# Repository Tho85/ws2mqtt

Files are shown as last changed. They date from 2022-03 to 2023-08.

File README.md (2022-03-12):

# ws2mqtt - WiSafe2 to MQTT gateway

ws2mqtt is an inofficial gateway to connect WiSafe2 smoke, heat and CO detectors to your smart home.

The gateway consists of an ESP32 module that handles Wifi and MQTT communication and integrates with Home Assistant through MQTT auto discovery. It is connected to an Arduino that acts as an SPI/UART converter. The Arduino talks to an official WiSafe2 module that is connected to your smoke detector network.

## Disclaimer

This project is not related to or endorsed by the manufacturer of WiSafe2 devices. It is an unofficial hobby project.

:warning: **DO NOT USE THIS PROJECT FOR SAFETY-CRITICAL PURPOSES!** :warning:

This is a hobby project after all, so do not rely on it for your personal safety or the saftey of others. Always assume that it will not work in a case of emergency, and plan your emergency procedures accordingly. As the [license](LICENSE.md) states in more detail, I won't be liable for any damages incurred by this project.

## Pictures

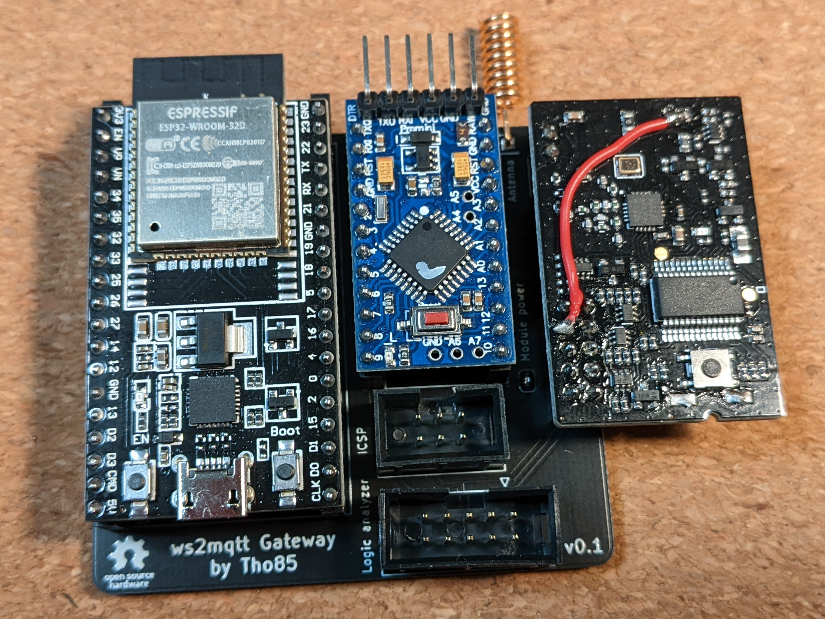
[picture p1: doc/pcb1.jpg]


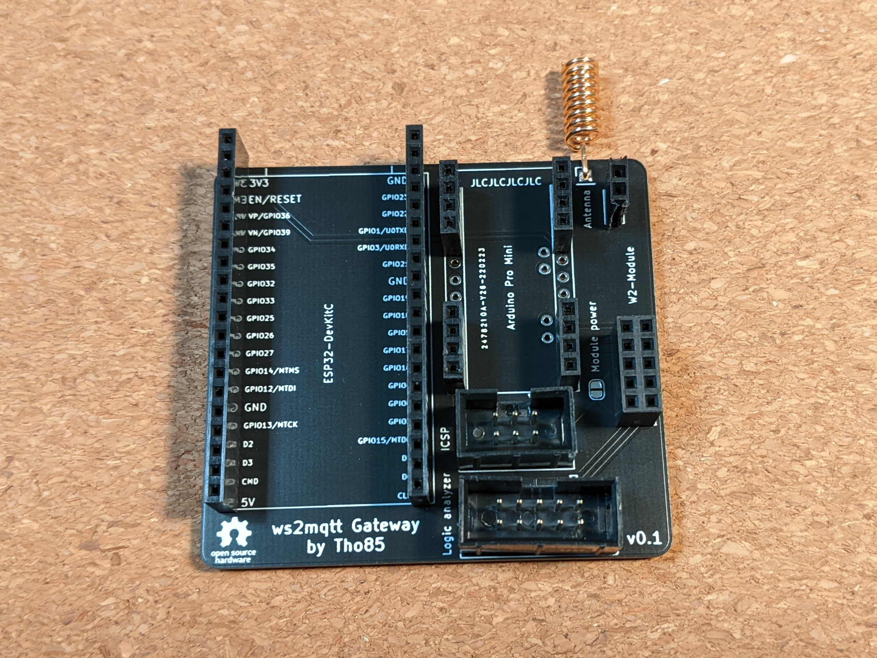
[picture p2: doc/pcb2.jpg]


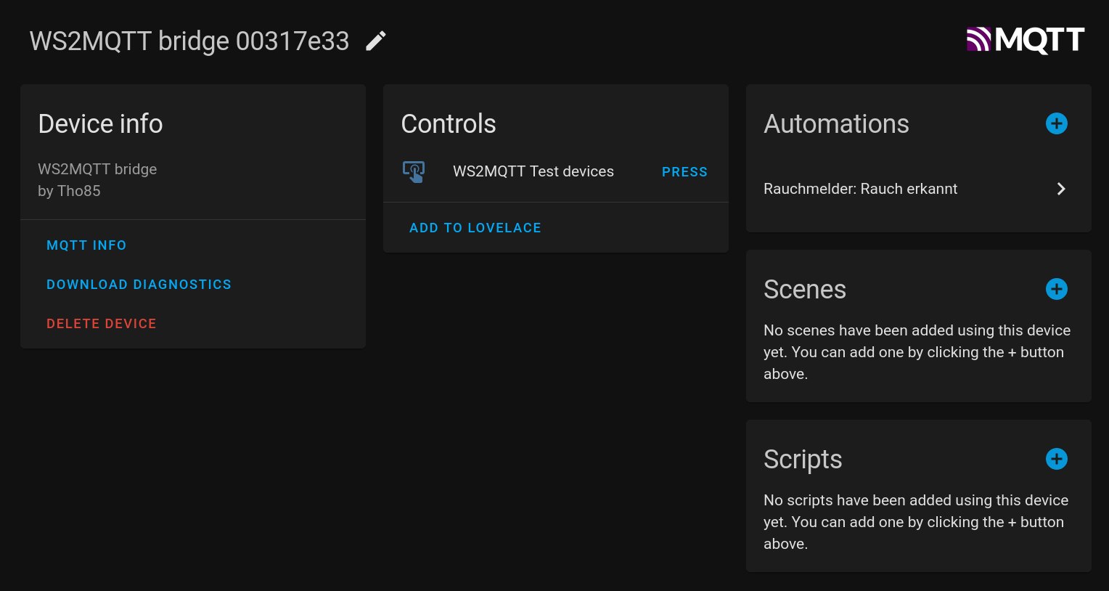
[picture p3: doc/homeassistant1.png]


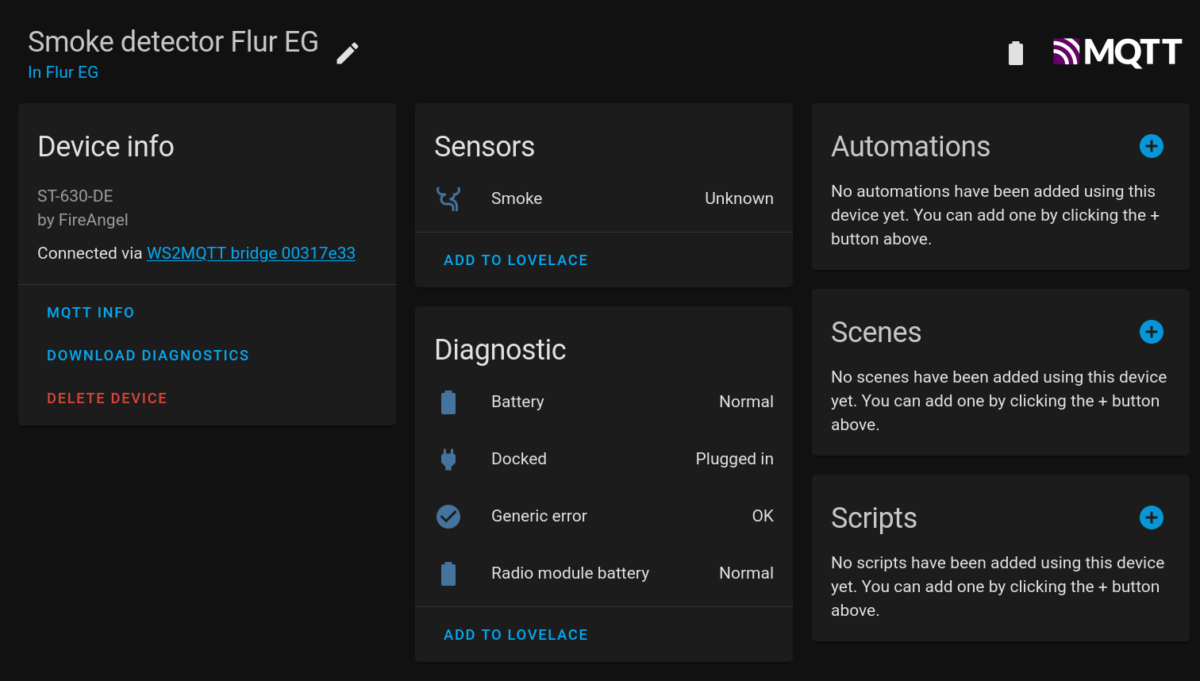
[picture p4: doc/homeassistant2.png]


## Supported devices

Tested:

- ST-630-DE(P) Smoke detector
- HT-630-EUT Heat detector

Not tested, but should be working:

- WST-630 Smoke alarm
- W2-CO-10X CO alarm
- FP1720W2-R Smoke alarm
- FP2620W2-R Smoke alarm

## Features

- [x] Smoke / heat detector states:
  - [x] Smoke / heat detected
  - [x] Battery state
  - [x] Radio module battery state
  - [x] Device attached to base
- [x] Test button detection
- [x] Combined test button / detection event (see Tips & troubleshooting)
- [x] Test all devices from Home Assistant

TODO:

- [ ] Test single device from Home Assistant
- [ ] Logging via MQTT
- [ ] ESP32 over-the-air updates

## Additional Hardware required

- [ESP32-DevKitC V4](https://docs.espressif.com/projects/esp-idf/en/latest/esp32/hw-reference/esp32/get-started-devkitc.html)
- [Arduino Pro Mini](https://www.arduino.cc/en/pmwiki.php?n=Main/ArduinoBoardProMini), or chinese clone
- [WiSafe2 module](https://www.directtradesupplies.co.uk/product.php/199997/fireangel-wisafe2-module--wireless-alarm-pairing--all-wisafe2--mains---battery-only--alarms-can-be-paired---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)
- A 868 MHz antenna, e.g. stripped from a defective detector. Alternatively, an 8.8 cm long wire
- Custom PCB (see `PCB` folder). Alternatively, lots of breadboard wires (see [schematic](PCB/schematic.pdf))

## Setup

- Setup Arduino
  - Mount Arduino to PCB
  - Flash Arduino firmware (see `Firmware-Atmega` folder) via programmer
- Setup ESP32
  - Mount ESP32 to PCB
  - Configure your secrets in `Firmware-ESP/include/credentials.h` (see example)
  - Flash ESP32 firmware (see `Firmware-ESP` folder) via USB
- Power board via ESP32 USB connector
- Setup WiSafe2 module
  - Mount WiSafe2 module to PCB
  - Join WiSafe2 network
    - Push button on module for 5 seconds
    - Module LED should light up
    - Within 5 seconds, push test button on a different detector
    - Module LED should blink multiple times as a confirmation
- Mount ESP32, Arduino and WiSafe2 module on PCB
- Configure Home Assistant
  - The gateway and all detectors should be visible in the "Devices" tab
  - Create an automation that listens for the `alarm` event emitted by the gateway, see below

## Tips & troubleshooting

* The recommended way to react to smoke detection and test events in Home Assistant is to listen to the `alarm` event emitted by the `ws2mqtt Bridge` device. This event is fired when any of the connected detectors detects smoke, or when any of the detectors' test buttons is pressed. This way you can test your emergency scenes and automations by pressing a detector's test button.

* _The "smoke detected" sensor shows an unknown state_

  This is actually a deficiency of the WiSafe2 protocol. As far as I know, there is no way to query a device for the current smoke / heat detector state. Additionally, a "smoke detected" message is only sent once to other detectors, and not repeated later. So if you start the gateway while a "smoke detected" event is ongoing, there is no way for the gateway to know about that event. I decided to err on the side of caution and show the state of devices as "unknown".

* _The "battery" sensor, "docked" sensor etc. show an unknown state_

  To conserve battery power, the gateway does not actively query the state of these diagnostic sensors. The sensor state is only updated on change. The easiest way to force an update is to remove a detector from its base, wait a bit, and re-mount the device. This should update not only the "docked" sensor, but also the battery ones.

* What is the programming language you used, and why is it not perfect C?

  C is not my mother tongue, so it's nearly certain that there are race conditions, buffer overflows or bad C programming practices in the code. Feel free to file an issue to point things out, or even better file a pull request.

## License

See [LICENSE](LICENSE.md).

## Final notes

Shout out to **C19HOP** and his [WiSafe2-to-HomeAssistant-Bridge](https://github.com/C19HOP/WiSafe2-to-HomeAssistant-Bridge), for helping in reversing the protocol, and for giving me the motivation to finish this project I've been working on for the last months.

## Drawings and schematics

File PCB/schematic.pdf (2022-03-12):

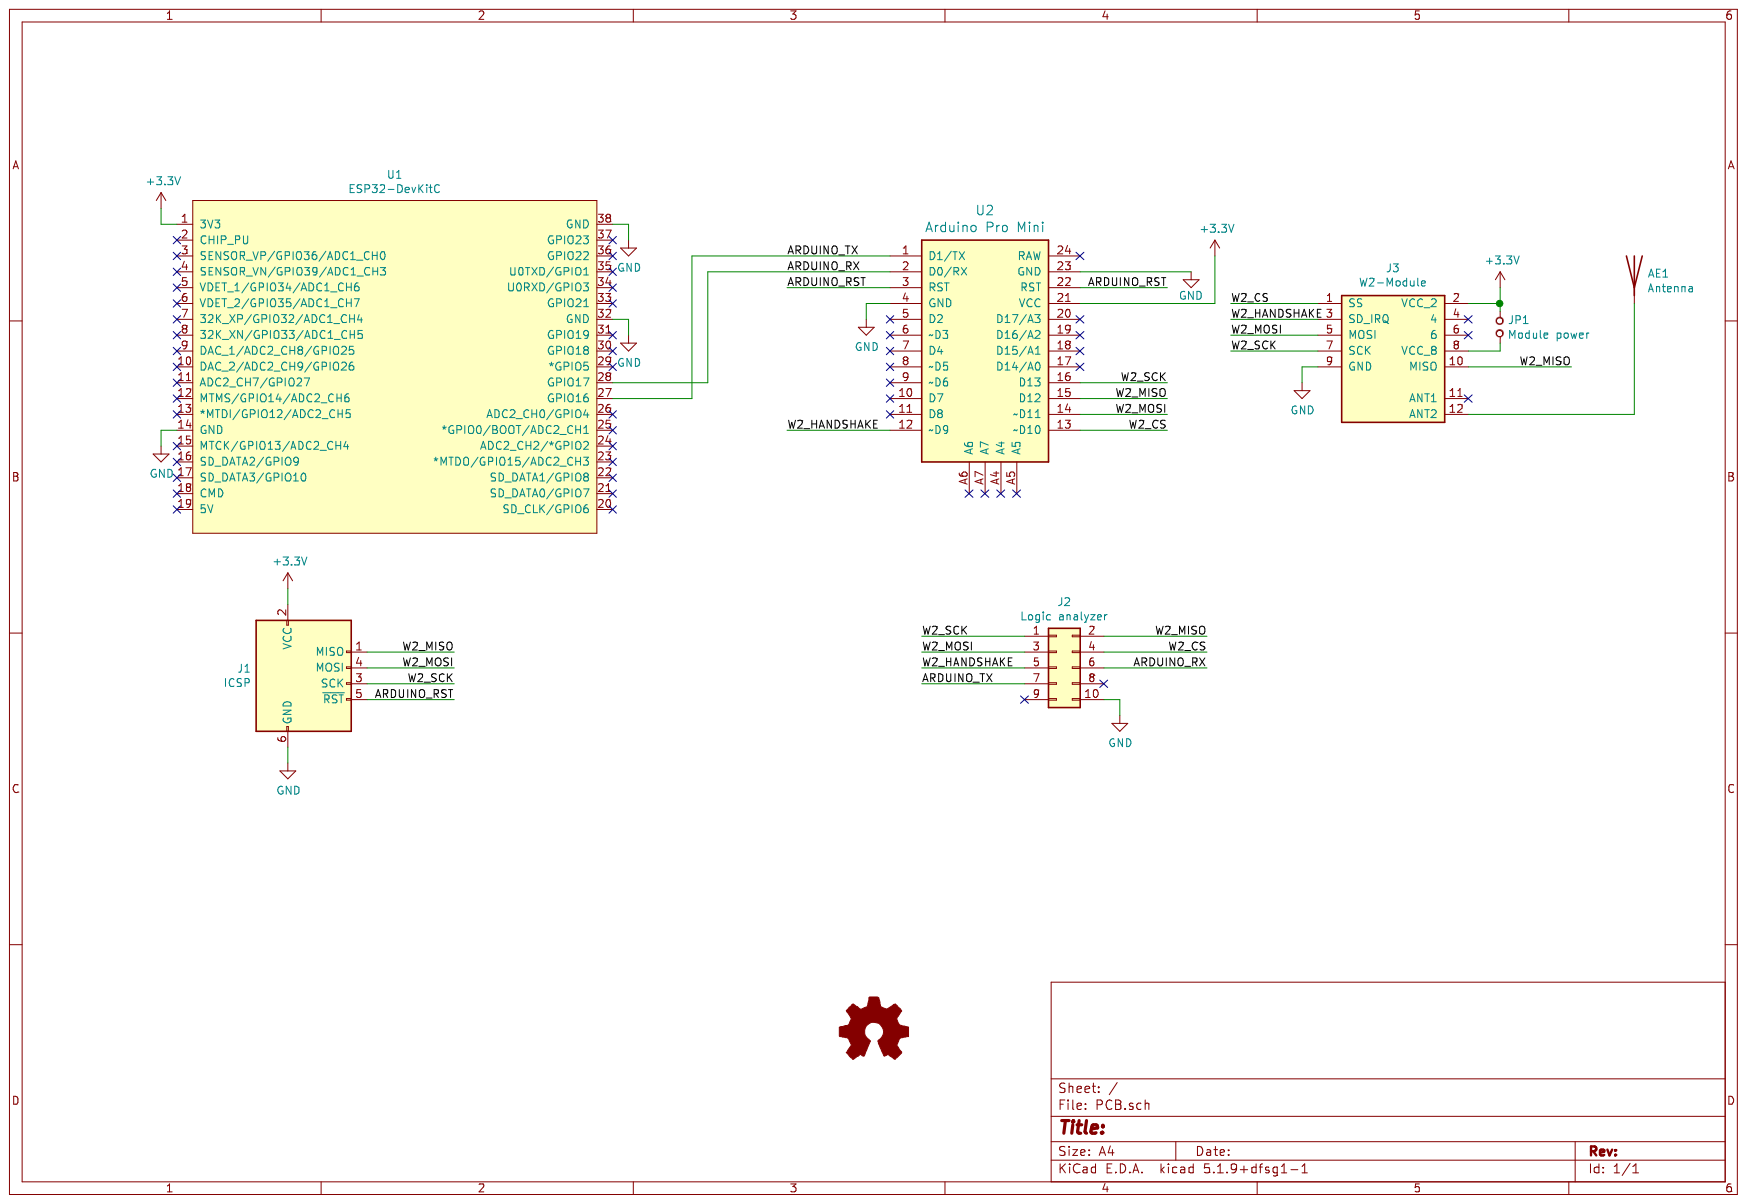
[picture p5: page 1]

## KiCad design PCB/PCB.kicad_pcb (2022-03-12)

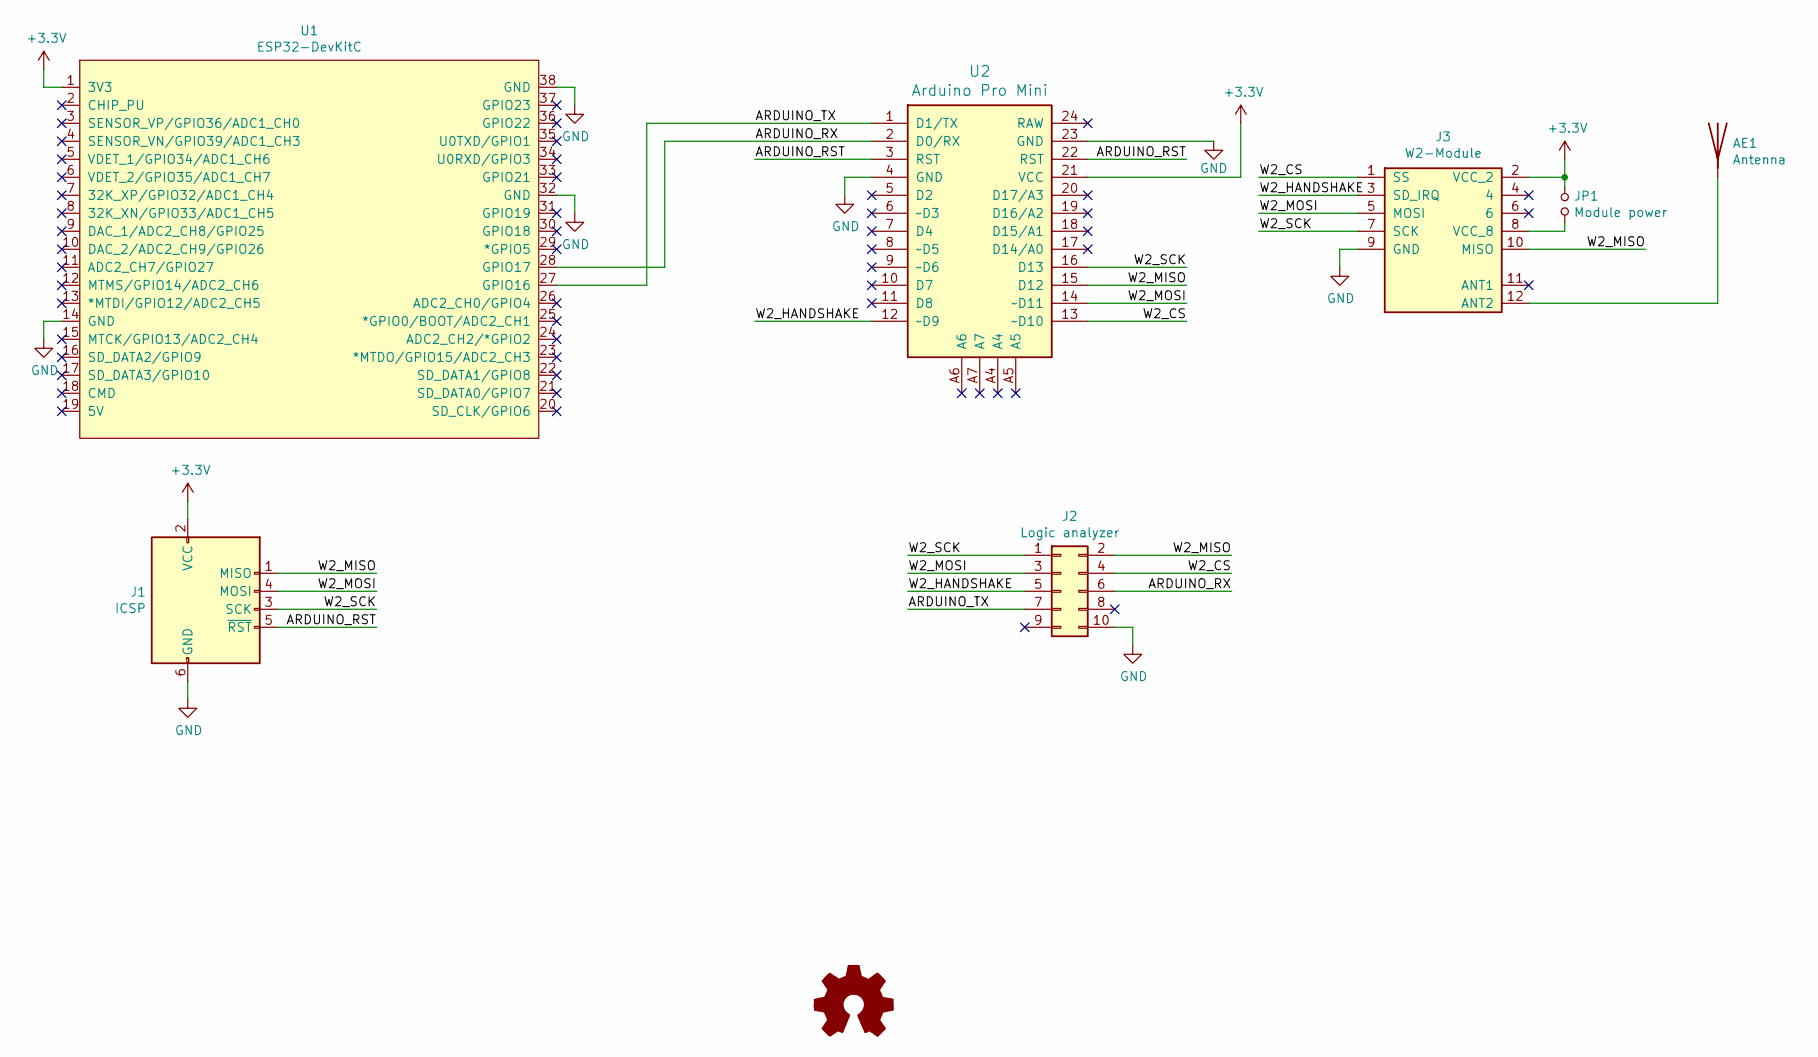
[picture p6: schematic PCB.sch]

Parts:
AE1: Antenna; PinHeader_1x01_P2.54mm_Vertical
J1: ICSP; IDC-Header_2x03_P2.54mm_Vertical
J2: Logic analyzer; IDC-Header_2x05_P2.54mm_Vertical
J3: W2-Module; W2-MM
JP1: Module power; SolderJumper-2_P1.3mm_Open_RoundedPad1.0x1.5mm
LOGO1: Logo_Open_Hardware_Small; OSHW-Logo_5.7x6mm_SilkScreen
U1: ESP32-DevKitC
U2: Arduino Pro Mini; Arduino_Pro_Mini

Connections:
+3V3: J1.2 (VCC), J3.2 (VCC_2), JP1.1, U1.1 (3V3), U2.21 (VCC)
/ARDUINO_RST: J1.5 (~RST), U2.3 (RST), U2.22 (RST)
/ARDUINO_RX: J2.6, U1.28 (GPIO17), U2.2 (D0/RX)
/ARDUINO_TX: J2.7, U1.27 (GPIO16), U2.1 (D1/TX)
/W2_CS: J2.4, J3.1 (SS), U2.13 (~~D10)
/W2_HANDSHAKE: J2.5, J3.3 (SD_IRQ), U2.12 (~~D9)
/W2_MISO: J1.1 (MISO), J2.2, J3.10 (MISO), U2.15 (D12)
/W2_MOSI: J1.4 (MOSI), J2.3, J3.5 (MOSI), U2.14 (~~D11)
/W2_SCK: J1.3 (SCK), J2.1, J3.7 (SCK), U2.16 (D13)
GND: J1.6 (GND), J2.10, J3.9 (GND), U1.14 (GND), U1.32 (GND), U1.38 (GND), U2.4 (GND), U2.23 (GND)
unnamed: AE1.1, J3.12 (ANT2)
unnamed: J3.8 (VCC_8), JP1.2

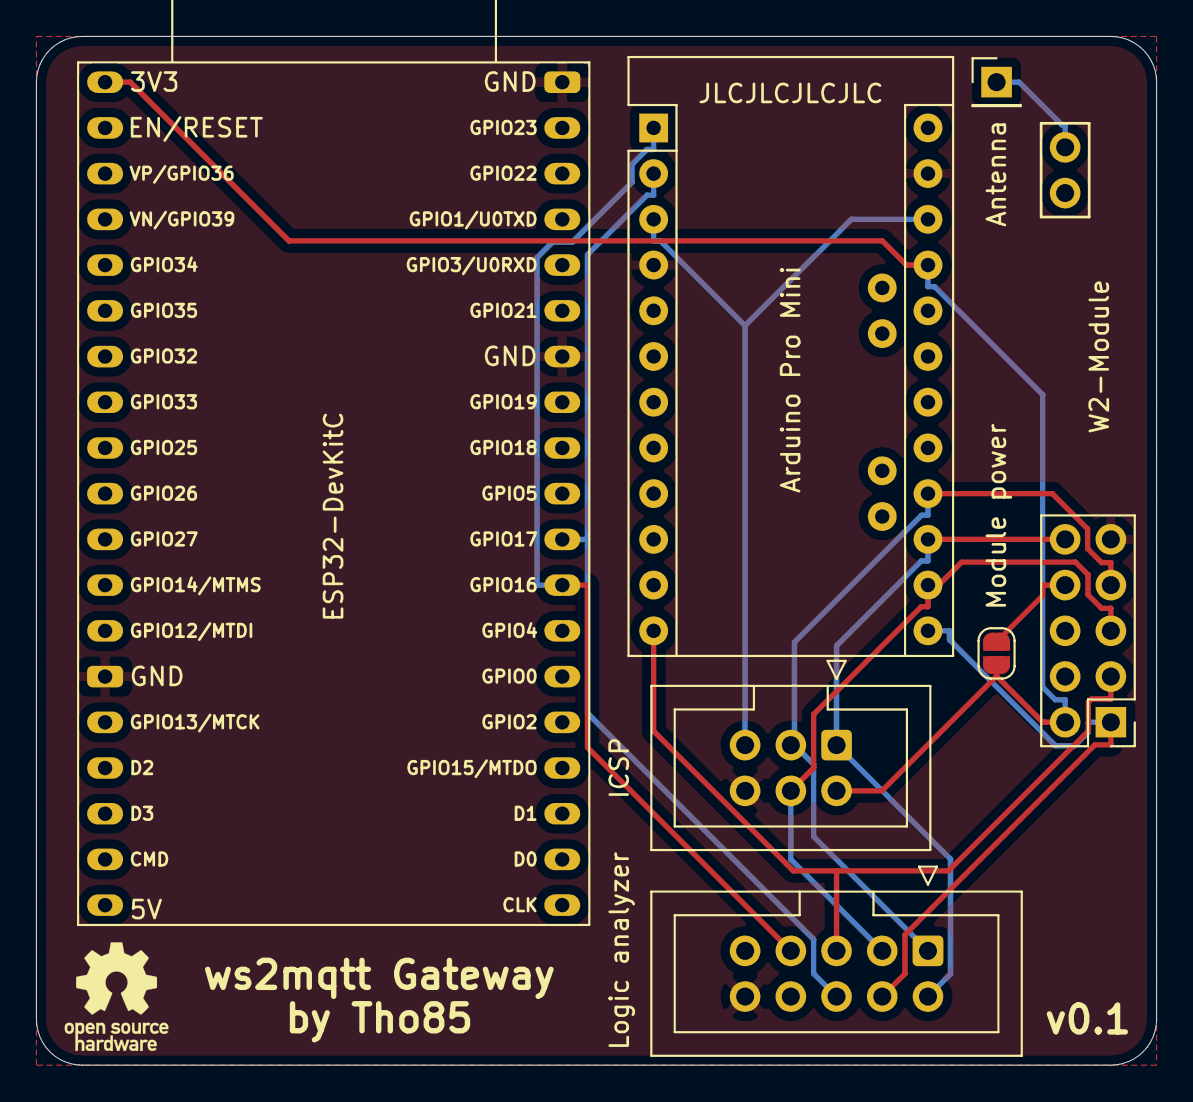
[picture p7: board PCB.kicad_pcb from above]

Board: 2 copper layers, 62.2 x 57.2 mm, 8 parts (0 on the bottom side), 12 nets.

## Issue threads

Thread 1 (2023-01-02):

WT32-ETH01 instead of ESP32-DevKitC V4 ?

m-s-e, 2023-01-02:
Hi there, more of a question realy...

I have used a few WT32-ETH01 units which have been supported by ESPHome and WLED for a a while now. They are not perfect, but i prefer the wired Ethernet connection to Wi-Fi.

I wonder if it might be quite easy to use a WT32-ETH01 instead of the ESP32-DevKitC V4 in your project. As far as i can see, the main issue is that you've used GPIO 16 & 17 from the ESP32 to the Arduino. These GPIOs aren't available on the WT32-ETH01, so i would need to swap them out to another two GPIOs (maybe 14 & 15).

I'm not a coder, and i can't find where the GPIOs are set in your code - but i guess they are set somewhere? Any pointers would be appreciated!

Cheers - MSE

Tho85, 2023-01-02:
GPIO 16 and 17 correspond to the ESP32's third UART port (RX2/TX2). The ports are not specified directly in my code directly but indirectly by using `Serial2` in the [ESP firmware](https://github.com/Tho85/ws2mqtt/blob/main/Firmware-ESP/src/spi_uart.cpp#L16-L17). The first serial port (RX0/TX0) is mainly used for debugging / development purposes all over the code.

According to the [docs](https://files.seeedstudio.com/products/102991455/WT32-ETH01_datasheet_V1.1-%20en.pdf) the WT32-ETH01 also exposes two serial ports, the first one on RX0/TX0 and the second one on RXD/TXD. The latter, however, seems to be mapped to GPIO17 (TXD) and GPIO5 (?) (RXD) on the WT32-S1 module, which doesn't make any sense to me.

To make it work with your module, you might want to try this:
* Remove / comment out all occurrences of `Serial` in the Firmware-ESP folder,
* Replace `Serial2` with `Serial` in the Firmware-ESP folder
* Connect the arduino to the pins RX0/TX0 on your WT32-ETH01 module (RX on the WT32-ETH01 <-> TX on the Arduino; TX on the WT32-ETH01 <-> RX on the Arduino)

A drawback is that you won't be able to debug the firmware, but this is not really necessary unless you want to develop new features.

m-s-e, 2023-01-03:
Many thanks for the detailed reply. I'll take a look, and report back with my progress! It won't be for a few weeks though...

I have two immediate queries:

1. I can't work out from the docs, why you think WT32-ETH01 exposing RXD/TXD on GPIO17 (TXD) and GPIO5 (RXD) is different from the ESP32-DevKitC V4 exposing the ESP32's third UART port (RX2/TX2) on GPIO 16 and 17. (obviously it's a different serial port, but what else is different?) https://docs.espressif.com/projects/esp-idf/en/latest/esp32/_images/esp32-devkitC-v4-pinout.png
2. in the WT32-ETH01 docs, how can you/I tell which serial port is which? e.g. `Serial` or `Serial2` etc

Thanks again

Tho85, 2023-01-03:
The ESP32-DevKitC V4 contains a daughter chip "ESP32-WROOM-32D", which in turn contains the original ESP32 chip.
GPIO16 on the original ESP32 chip functions as the chip's `U2RXD` pin, as can be seen in the [datasheet](https://www.espressif.com/sites/default/files/documentation/esp32_datasheet_en.pdf) (p. 16):
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
As to my knowledge, there's no way to change that in either hardware or software. This pin is exposed via the ESP32-WROOM-32D chip and connected to the ESP32-DevKitC V4 pin labelled `16`. --> `U2RXD` is available on pin 16.

The WT32-ETH01 on the other hand contains a daughter chip "WT32-S1", which in turn contains the original ESP32 chip. The WT32-S1 exposes both GPIO16 and GPIO05 of the underlying ESP32 chip (see  [datasheet](https://www.tinytronics.nl/shop/index.php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) p. 7-8). However, the WT32-ETH01 only exposes GPIO05 at the pin labelled `RXD` ([datasheet](https://files.seeedstudio.com/products/102991455/WT32-ETH01_datasheet_V1.1-%20en.pdf) p. 9). --> `U2RXD` seems to be unavailable on any of the WT32-ETH01 pins.

m-s-e, 2023-01-11:
Thanks for the further insight. I'll try and make some progress and report back!!

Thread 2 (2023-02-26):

Silence alarms?

shred, 2023-02-26:
For a long time I am looking for a good smoke alarm solution that integrates well into my home automation. The FireAngel and your ws2mqtt bridge finally seems to be what I am looking for. Thank you for your project!

I have a question: As far as I can see, ws2mqtt can read the status, report alarms and trigger test alarms. Is it also possible to silence an actual alarm?

Reason: If I am not at home (in safety, e.g. on a vacation), I'd like to be able to silence a confirmed false alarm, to avoid that neighbours are calling the fire brigade for nothing.

Tho85, 2023-02-26:
The WiSafe protocol supports silencing all alarms remotely, as well as silencing only those devices that were not the source of the alarm. However, I have deliberately not implemented that functionality. From my perspective a sounding alarm is always worth checking out in person, either by a friendly neighbour or the fire brigade.

However, speaking from a technical perspective, it should be possible to implement this.

shred, 2023-02-26:
Thanks! I share your concerns. I would only silence an alarm remotely if I was **absolutely** sure it was false (e.g. by inspecting the room via surveillance camera first, and keep monitoring it for a while).

Could you add the feature, and maybe disable it by default via `#define`, so one would have to actively enable it?

I could also do a fork and add it there, but I would then need your help about what to add.

Tho85, 2023-02-26:
Hi, a compile time switch (e.g. with a `#define`) sounds like a good idea. Unfortunately, after digging through my logic analyzer dumps, it seems I have never actually captured the required commands to silence the alarm. If someone would happen to capture that command by hooking into the communication between radio module and smoke detector, the following steps would be necessary to implement the functionality

* Implement the WiSafe2 packet structure in `Firmware-ESP/include/wisafe2_packets.h`
* Implement a function in `Firmware-ESP/src/wisafe2_tx.cpp` that sends this packet
* Announce a new button entity from `Firmware-ESP/src/homeassistant.cpp`
* Subscribe to the announced MQTT topic in `Firmware-ESP/src/homeassistant.cpp` and call the function implemented above

shred, 2023-02-26:
I can try to do that, and then send a pull request. However I just ordered the smoke detectors and hardware components today, so it might take a while until I got everything set up and figured out how it works. If someone else is faster, please don't wait for me. :smiley:

Do I need to have the control unit to send the commands? I only ordered smoke detectors, and the corresponding WiSafe2 modules. (I ordered ST-632-DET detectors, I hope they're still compatible to the ST-630-DE model mentioned in the README.)

Tho85, 2023-02-26:
> The WiSafe protocol supports silencing all alarms remotely,

This would require a control unit like the W2-WTSL-1EU which can silence all alarms (at least according to its manual)

> as well as silencing only those devices that were not the source of the alarm.

This will only require a ST-632-DET detector + module since pressing the test button during an alarm will silence all other alarms except for the one detecting smoke.

Feel free to open a PR :+1:

MattFryer, 2024-10-28:
I've added this (smoke and CO devices) in pull request #5

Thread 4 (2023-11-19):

homeassistent reboot problem.

s4saken, 2023-11-19:
Hi,

Great project!.

It got me back into soldering, and made my choice for smoke detectors pretty clear.
Everything went smooth and the mqtt discovery in home assistant works like a charm.

Problem/Request:

After i restart home assistant, the sensor values are not there, this is because the messages are not retained.
Although this is not a problem, i do have to restart the bridge to make them appear again.

Could you make it subscribe to topic homeassistant/status and do a reboot or republish on value "online"?

I solved this with a power plug, but its unnecessary.

The solution also seems like a great feature, since you made it for homeassistent.

Kind Regards,

MattFryer, 2024-11-02:
I've added this in pull request #5

It subscribes to the topic "homeassistant/status" and publishes all the cached device statuses

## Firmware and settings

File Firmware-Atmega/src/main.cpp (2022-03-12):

#include "Arduino.h"
#include "SPI.h"

#define LED_BUILTIN 13
#define ENABLE_MODULE_PIN 8
#define HANDSHAKE_PIN 9
// #define SPI_DEBUG

unsigned long lastReceivedAt = 0;

#define STOP_WORD 0x7E
#define RECEIVE_TIMEOUT_US 10000

#define SPI_BUFFER_SIZE 32
uint8_t recvbuf[SPI_BUFFER_SIZE];
volatile byte recvbufPos;

uint8_t sendbuf[SPI_BUFFER_SIZE];
volatile byte sendbufPos;

#define SERIAL_BUFFER_SIZE 128
uint8_t serialbuf[SERIAL_BUFFER_SIZE];
byte serialbufPos;

char nibble1;

volatile boolean processReceiveFinished;
volatile boolean processReceived;
volatile boolean processSent;
volatile boolean sendData;

bool binModeStarted = false;
unsigned int binModeExpectedLength = 0;

void send(uint8_t *data, int length) {
	Serial.print("> ");
	for(int i = 0; i < length; i++) {
		if (data[i] < 0x10) Serial.print("0");
		Serial.print (data[i], HEX);
		Serial.print(" ");
	}
	Serial.println("");

	// Initialize sending register
	memcpy(sendbuf, data, length);
	sendbufPos = 0;

	// Put first byte into SPI register
	SPDR = sendbuf[0];
#ifdef SPI_DEBUG
	Serial.print(">. ");
	Serial.println(sendbuf[0], HEX);
#endif

	sendData = true;
	digitalWrite(HANDSHAKE_PIN, HIGH);
}

void setup() {
	pinMode(LED_BUILTIN, OUTPUT);
	digitalWrite(LED_BUILTIN, LOW);

	pinMode(ENABLE_MODULE_PIN, OUTPUT);
	digitalWrite(ENABLE_MODULE_PIN, HIGH);

	pinMode(HANDSHAKE_PIN, OUTPUT);

	Serial.begin(19200);
	pinMode(MISO, OUTPUT);

	SPCR |= _BV(SPE);

	// Initialize SPI buffers
	recvbufPos = 0;
	memset(recvbuf, 0x00, SPI_BUFFER_SIZE);

	sendbufPos = 0;
	memset(sendbuf, 0x00, SPI_BUFFER_SIZE);

	serialbufPos = 0;
	memset(serialbuf, 0x00, SERIAL_BUFFER_SIZE);

	processReceiveFinished = false;
	processReceived = false;
	processSent = false;
	sendData = false;

	SPI.attachInterrupt();
}

ISR (SPI_STC_vect) {
	digitalWrite(HANDSHAKE_PIN, LOW);

	// Read received char into receiving buffer
	byte c = SPDR;
	recvbuf[recvbufPos] = c;

	if (sendData) {
		processSent = true;
	} else {
		processReceived = true;
	}
}

void loopSPI() {
	if (processReceived) {
#ifdef SPI_DEBUG
		Serial.print("<. ");
		Serial.println(SPDR, HEX);
#endif
		recvbufPos += 1;
		recvbufPos %= SPI_BUFFER_SIZE;

		lastReceivedAt = micros();

		// Signal transaction received
		digitalWrite(HANDSHAKE_PIN, HIGH);
		digitalWrite(HANDSHAKE_PIN, LOW);

		// End of message received, stop processing
		if (SPDR == STOP_WORD)
			processReceiveFinished = true;

		processReceived = false;
	}

	if (processReceiveFinished) {
		Serial.print("< ");
		for(int i = 0; i < recvbufPos; i++) {
			if (recvbuf[i] < 0x10) Serial.print("0");
			Serial.print (recvbuf[i], HEX);
			Serial.print(" ");
		}
		Serial.println("");

		Serial.print("{");
		Serial.print((char) recvbufPos);
		for(int i = 0; i < recvbufPos; i++) {
			Serial.print ((char)recvbuf[i]);
		}
		Serial.println("");

		recvbufPos = 0;
		processReceiveFinished = false;
		lastReceivedAt = 0;
	}

	if (processSent) {
		if (sendbuf[sendbufPos] == STOP_WORD) {
			// Finished sending
			sendData = false;
			processSent = false;
		} else {
			// Advance send buffer
			sendbufPos += 1;
			sendbufPos %= SPI_BUFFER_SIZE;

			// Set new char
			SPDR = sendbuf[sendbufPos];
#ifdef SPI_DEBUG
			Serial.print(">. ");
			Serial.println(sendbuf[sendbufPos], HEX);
#endif

			// Trigger send
			digitalWrite(HANDSHAKE_PIN, HIGH);

			processSent = false;
		}
	}

	if (lastReceivedAt > 0 && micros() - lastReceivedAt > RECEIVE_TIMEOUT_US) {
		processReceiveFinished = true;
		processReceived = false;
	}
}

char nibble2c(char c)
{
   if ((c>='0') && (c<='9'))
      return c-'0' ;
   if ((c>='A') && (c<='F'))
      return c+10-'A' ;
   if ((c>='a') && (c<='f'))
      return c+10-'a' ;
   return -1 ;
}

char hex2c(char c1, char c2)
{
   if(nibble2c(c2) >= 0)
     return nibble2c(c1)*16+nibble2c(c2) ;
   return nibble2c(c1) ;
}

String hex2str(char *data)
{
   String result = "" ;
   for (int i=0 ; data[i] == ' ' || nibble2c(data[i])>=0 ; i++)
   {
      if (data[i] == ' ') continue;
      result += hex2c(data[i],data[i+1]) ;
      if(nibble2c(data[i+1])>=0)
        i++ ;
   }
   return result;
}

void loop() {
	loopSPI();

	while (Serial.available()) {
		unsigned char c = Serial.read();
		if (binModeStarted) {
			if (binModeExpectedLength == 0) {
				serialbufPos = 0;
				memset(serialbuf, 0x00, SERIAL_BUFFER_SIZE);
				binModeExpectedLength = c;
			} else {
				// Receive char, end bin mode if length reached
				serialbuf[serialbufPos++] = c;
				if (serialbufPos == binModeExpectedLength) {
					send(serialbuf, serialbufPos);
					serialbufPos = 0;
					memset(serialbuf, 0x00, SERIAL_BUFFER_SIZE);
					binModeStarted = false;
					binModeExpectedLength = 0;
				}
			}
		} else {
			switch(c) {
				case ' ':
					continue;
				case '}':
					binModeStarted = true;
					break;
				case '\r':
					send(serialbuf, serialbufPos);

					nibble1 = 0x00;
					serialbufPos = 0;
					memset(serialbuf, 0x00, SERIAL_BUFFER_SIZE);
					break;

				default:
					if (nibble2c(c) != -1) {
						if (!nibble1)
							nibble1 = c;
						else {
							serialbuf[serialbufPos++] = hex2c(nibble1, c);
							nibble1 = 0x00;
						}
					}
					break;
			}
		}
	}
}

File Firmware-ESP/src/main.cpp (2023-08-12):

#include "Arduino.h"

#include "config.h"
#include "homeassistant.h"
#include "main.h"
#include "wifi_inc.h"
#include "spi_uart.h"
#include "wisafe2_rx.h"
#include "wisafe2_tx.h"
#include "device_db.h"

unsigned long lastSIDMapRequestedAt = 0;

void setup() {
	Serial.begin(19200);
	delay(500);
	setupDeviceDB();
	setupSPI();
	setupWifi();
	setupMQTT();

	sendDiagnosticRequest();
	sendQuerySIDMap();
}

void loopUpdateSIDMap() {
	if (millis() - lastSIDMapRequestedAt > QUERY_NEW_DEVICES_INTERVAL * 1000) {
		lastSIDMapRequestedAt = millis();

		sendDiagnosticRequest();
		sendQuerySIDMap();
	}
}

void loop() {
	receiveSPIMessage(&handleRX);
	loopMQTT();

	loopUpdateSIDMap();
	loopTX();
}

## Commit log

2022-03-12 Add PCB schematic
2022-03-12 Add antenna info to readme
2023-08-12 Rename "wifi.h" to avoid issues with Arduino framework (#3)
    * Update wisafe2_rx.cpp
    * Update wifi.cpp
    * Update main.cpp
    * Update homeassistant.cpp
    * Rename wifi.h to wifi_inc.h
    * Update README.md
    * Update README.md
    * Update Firmware-ESP/src/wifi.cpp
    ---------
    [main.cpp, wifi.cpp, wisafe2_rx.cpp]
